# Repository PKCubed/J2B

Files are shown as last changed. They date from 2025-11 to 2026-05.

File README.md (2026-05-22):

# J2B
### Wenatchee Seventh Day Adventist Church's Journey to Bethlehem Timekeeping Technology Systems

## Diagrams and Documentation
**A wiring diagram can be found [here](https://github.com/PKCubed/J2B/blob/master/J2B%20Wiring%20Diagram.pdf)**. This diagram shows the connections between many of the devices that need to be set up in the village every year, as well as connections that should be permanently set up.

**A wiring map can be found [here](https://github.com/PKCubed/J2B/blob/master/J2B%20Wiring%20Map.pdf)**. This diagram shows the connections in the village, and where each connection goes to and from on a high resolution aerial image of the village. *This diagram does not render the background image correctly in GitHub. It will likely need to be downloaded first.*

## System Overview
Journey to Bethlehem requires the actors to transition each group of journeyers along to the next part of their journey. The actors need to know when to do this, and keep the whole operation on a pretty rigid schedule. If things are out of sync, we’ll have too many groups in some areas, getting jumbled together, or not enough groups in the village, and we won’t be able to get through the number of groups we’d like to as fast as we would like to. There are a lot of people who want to experience Bethlehem, and getting everyone the opportunity is our goal.

In order to get all the groups through, a system for keeping everything synchronized and in time is necessary. In past years, this has been done with walkie-talkies given to specific actors called time-keepers in the village. Someone with a walkie-talkie would be watching a clock, and every 4 minutes or so, would say “30 30 30,” to let all the time-keepers in the village know that they had 30 seconds until the groups would need to move on, and “GO GO GO,” to let the time-keepers know it was time to move the groups to the next section of their journey. The advantages of this system were that, ideally, each time-keeper would be able to have an earpiece, and would be able to clearly hear the message. However, in practice, the walkie-talkie system was very spotty, and groups would end up out of sync.

In Christmas of 2024, we built a new system. Peter Kyle designed an automated system using little plastic candles, and audio cues in the village. These all connect to a controller that lives in the FLC (Family Life Center). The controller can be started in automatic mode (or manual mode) to make the candles flicker out in time to let the time-keepers in the village get the message. One candle burns out at “30 30 30,” and the other candle then burns out at “GO GO GO.” After about 10 seconds, both candles come back to a flickering flame again.

Controller
Candle

With this new system, a web interface was also built. People can open their web browser on their phone or computer and navigate to the public-facing web interface to view the timekeeping clock. People responsible for calling groups and setting the current performer text on the projector screen can also use this web interface to do this.

Screenshot of Web Interface

When a group gets called, it's important to get people's attention in the sanctuary. Putting up the big group number text on the screen is not quite enough to get people's attention if they aren't looking at it. To accomplish this, whenever a group is called, the program on the projection PC sends a GET request to the church Home Assistant server, which then is received by Node-RED, and triggers a Home Assistant script that brings the houselights and christmas lights up in brightness, and triggers an animation on the valance lights. After about 30 seconds, the houselights dim down again.

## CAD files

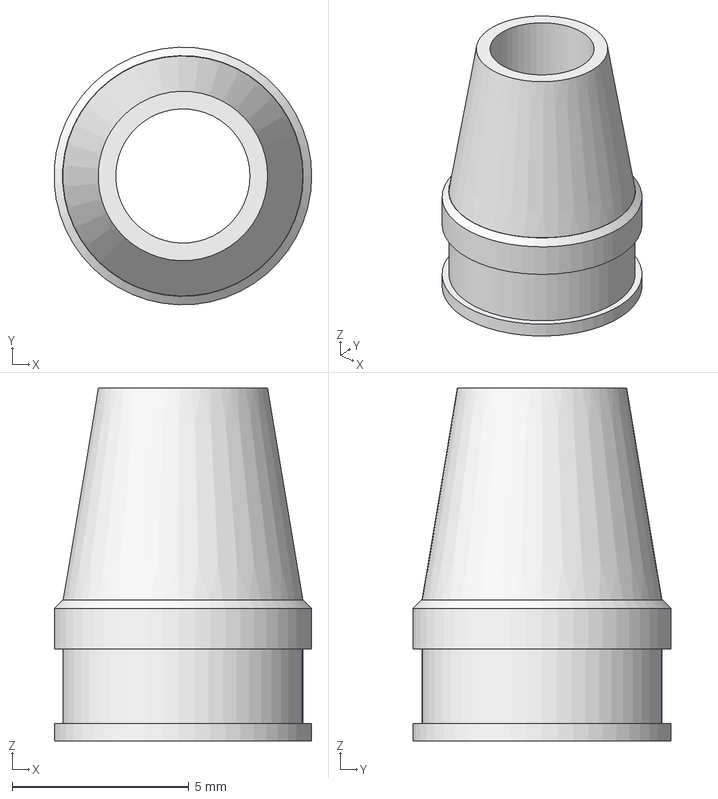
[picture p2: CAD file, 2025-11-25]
3D Models/TPU Cable Stress Relief.FCStd
7.29 x 7.30 x 10.0 mm

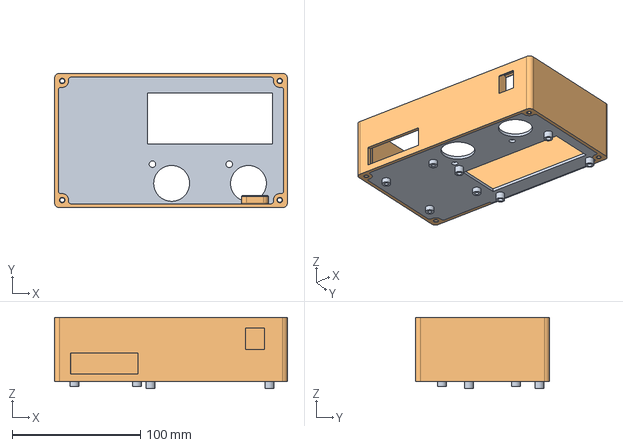
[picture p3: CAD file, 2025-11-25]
3D Models/j2b controller.FCStd
182.0 x 105.0 x 55.5 mm

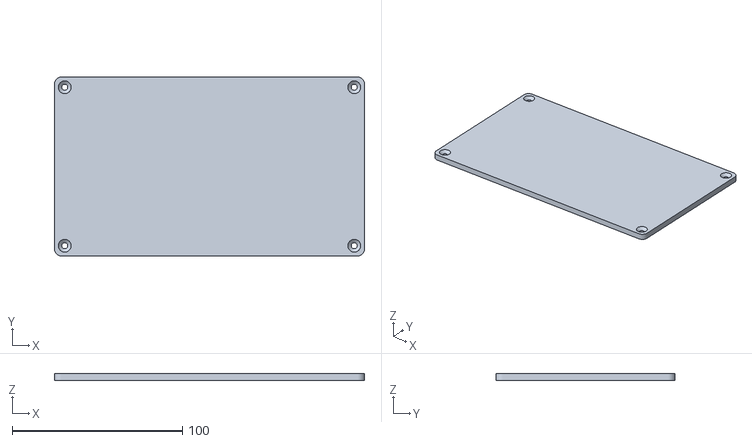
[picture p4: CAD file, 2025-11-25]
3D Models/j2b-controller-back-plate.stl
182.0 x 105.0 x 4.00

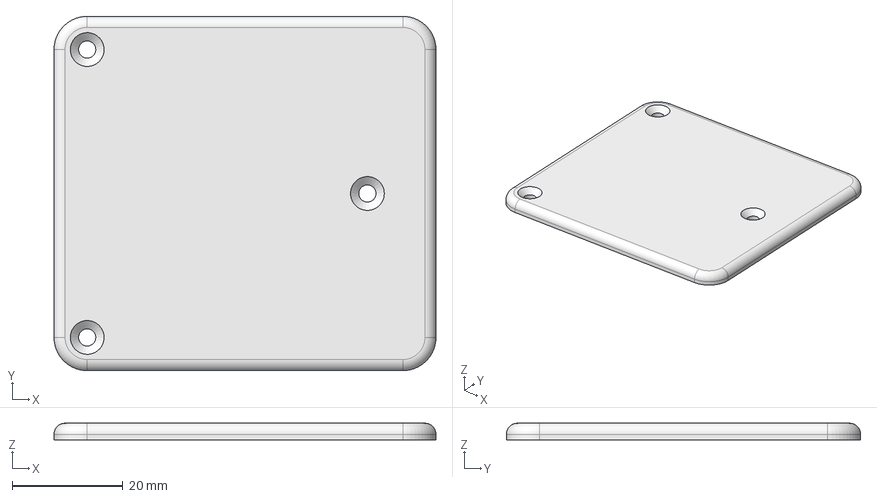
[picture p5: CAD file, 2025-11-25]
3D Models/Keystone Passthrough Lid.FCStd
69.0 x 64.0 x 3.00 mm

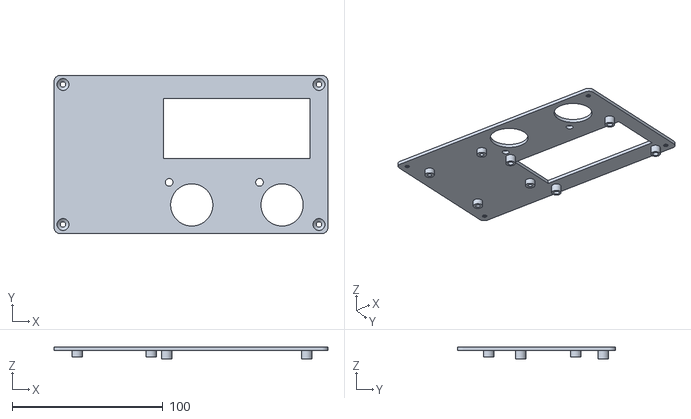
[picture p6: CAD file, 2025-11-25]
3D Models/j2b-controller-front-plate.stl
182.0 x 105.0 x 8.00

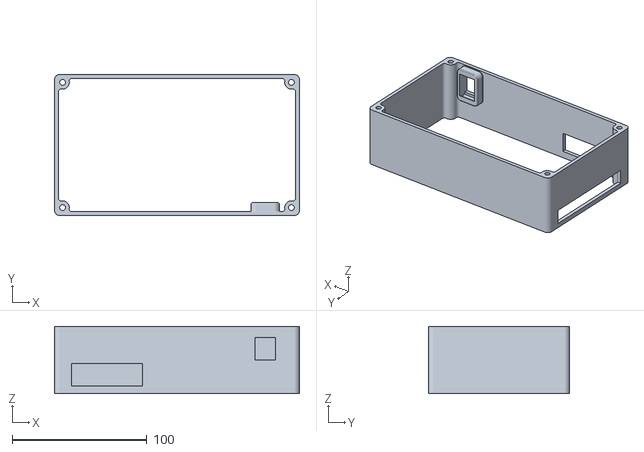
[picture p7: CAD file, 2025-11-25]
3D Models/j2b-controller-shell.stl
182.0 x 105.0 x 50.0

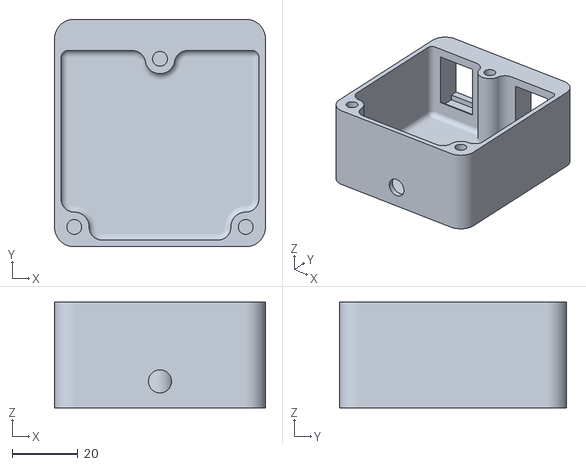
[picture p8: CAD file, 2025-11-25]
3D Models/keystone passthrough 2 corrected.stl
64.0 x 69.0 x 32.0

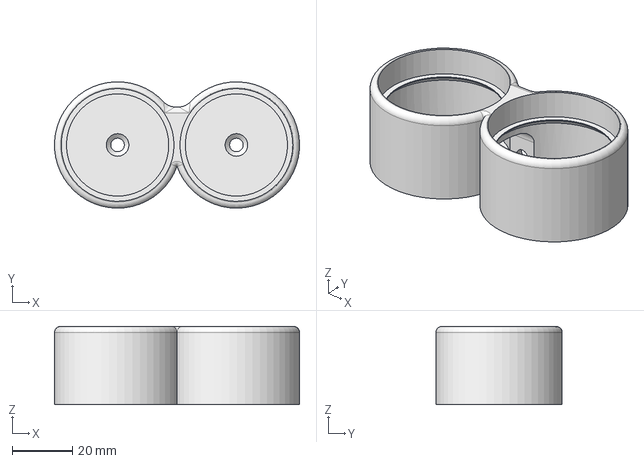
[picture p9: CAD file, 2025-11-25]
3D Models/Candle Holder.FCStd
81.5 x 42.0 x 26.0 mm

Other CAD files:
3D Models/TPU Cable Stress Relief.stl
3D Models/candle holder.stl

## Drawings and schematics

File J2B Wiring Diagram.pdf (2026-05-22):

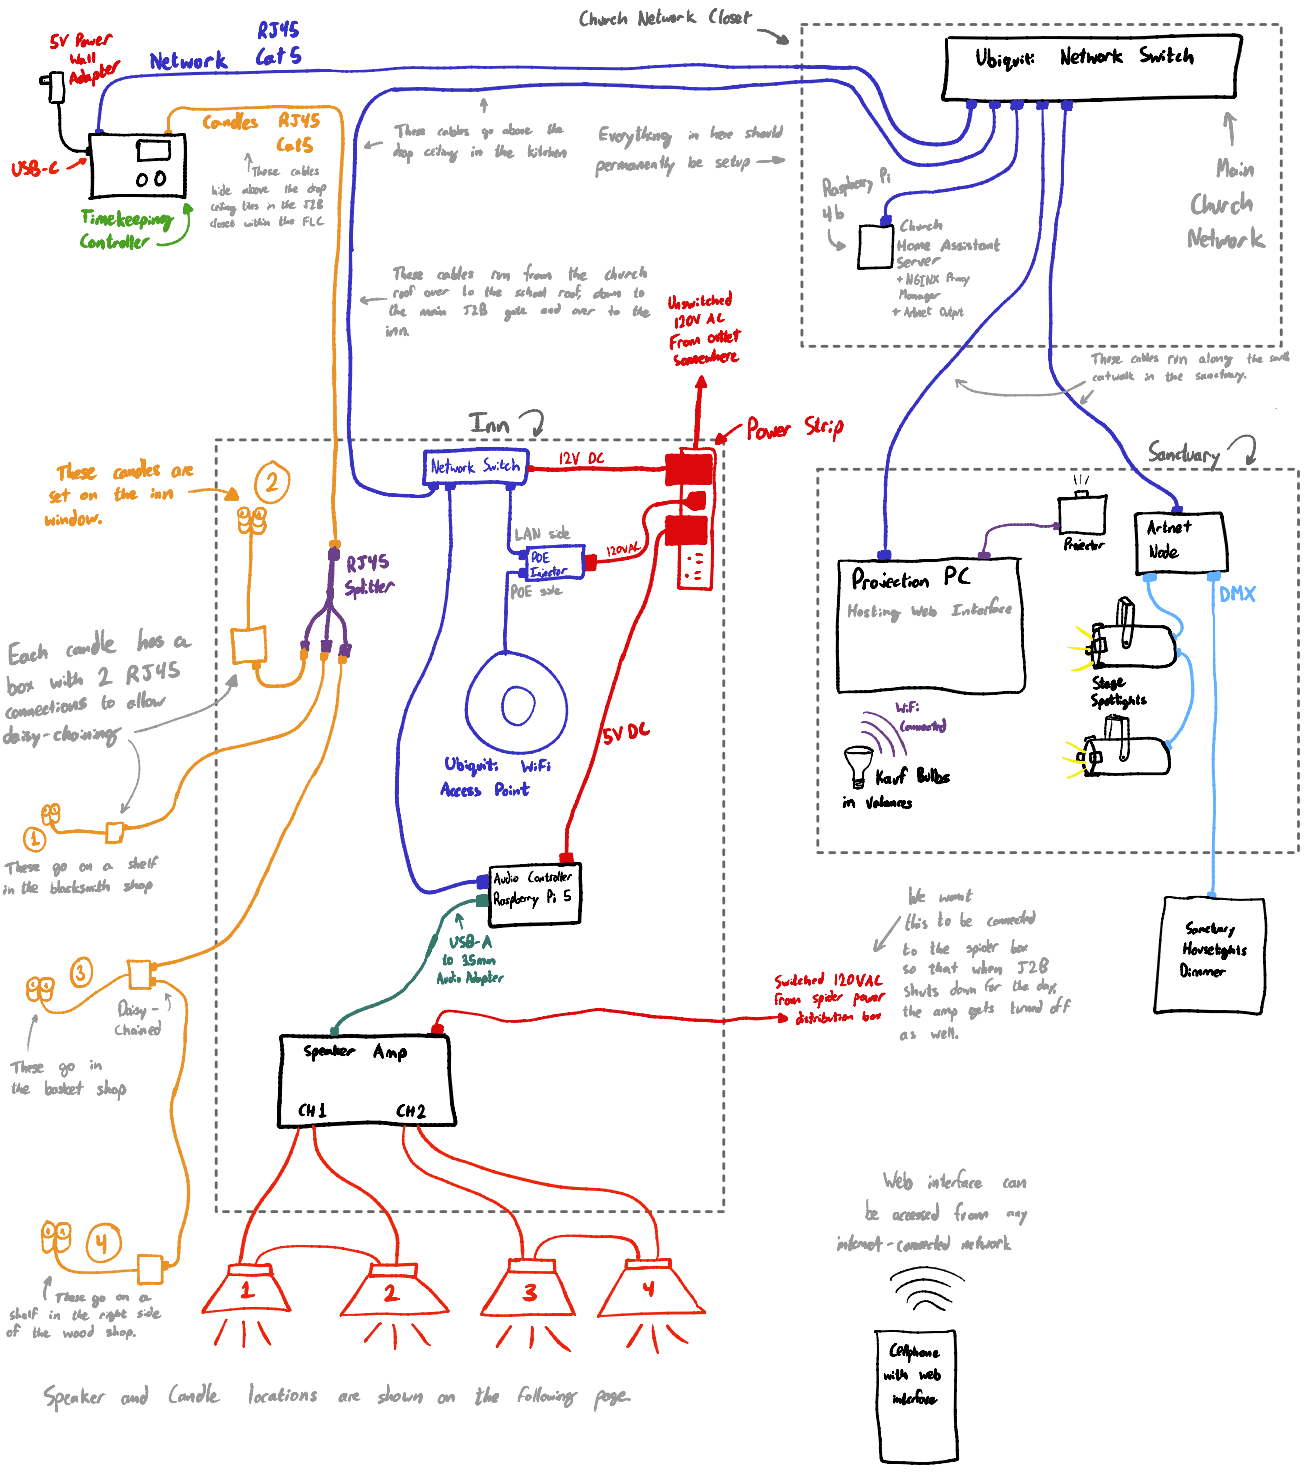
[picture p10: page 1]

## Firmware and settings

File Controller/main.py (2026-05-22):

"""
Written by Peter Kyle 2024 for Journey to Bethlehem Timekeeping
Wenatchee WA Seventh Day Adventist Church
Any questions or comments, please contact me at
peter@pkcubed.net
(***) ***-****
These contacts may not work in the future, but please try to reach out to me however possible.

Feel free to leave your name below to let others know that you've been here and what you did:
- Peter Kyle 2024
	If your seeing this, you're either really curious or something is not working... Good luck to you!
	This was a lot of fun to create and I hope it continues to be used in the distant future. J2B is a blessing to a lot of people.

	Description of this program:
	This is designed to run on a Raspberry Pi 4b with 2 buttons attached, each with an led, and a 20x4 character LCD.
	It's purpose is to control candles in the J2B village as well as audio cues to tell the groups to move on after 4 minutes.
	Traditionally this has been done by FRS radio with a timekeeper speaking into the radio "30 30 30" and "GO GO GO" when 30 seconds were left on the clock and when the 4 minutes had elapsed respectively.
	Hopefully this will prove to be a better solution, both easier to use, and more effective. I've heard that the radios were very much not reliable.
	This also sends the timekeeping time, or rather makes it available for other things to see. Primarily the computer in the balcony responsible for projection which has a program running on it for displaying the group number and the performers on stage.
	That program then has a web interface that allows users to modify the group number, change the performer, and show them the timekeeping time. This way they know when to call the next group of people from the sanctuary.
	This program sends GET requests to another raspberry pi which is responsible for playing the audio cues. It is connected to a speaker amp and a bunch of speakers.


"""

start_text="J2B Timekeeper Panel" # This is the text to be displayed at startup
running_text = "J2B Timekeeper Panel"

message = ""
last_message = ""

audio_player_ip_address = "10.12.2.1" # This is the IP address of the raspberry pi in the village that plays audio through speakers in the village. If this is not set correctly, audio will not work!

from RPLCD.i2c import CharLCD
import RPi.GPIO as GPIO
GPIO.setwarnings(False)
import time
start_time = time.time()
import math
import datetime
from flask import Flask
import threading
import requests

candles_1_pin = 22
candles_2_pin = 27

mode_button_pin = 24
mode_led_pin = 5
trigger_button_pin = 23
trigger_led_pin = 6

button_debounce_time = 0.100 # The duration to lengthen any button press to in order to reject button bouncing

total_duration = 4 *60 # 4 Minutes
timer_duration = 30 # 30 Seconds
go_duration = 10 # 10 Seconds

mode = "Manual"

trigger_timer = 0

trigger_button_state = 0
trigger_button_last_state = 0
trigger_button_debounce_timer = 0

mode_button_state = 0
mode_button_last_state = 0
mode_button_debounce_timer = 0
cycles = 0
cycles_pre_go = 0
last_count = total_duration + 1
last_status = ""

def send_message(text):
	global message
	tstamp = time.time()
	print(tstamp)
	message = (str(datetime.datetime.fromtimestamp(tstamp).strftime("%-H:%M:%S"))+"-"+text)[0:20]
	print(datetime.datetime.fromtimestamp(tstamp))
	

app = Flask(__name__)

@app.route('/')
def time_page():
	if trigger_timer:
		return str(time.time()-trigger_timer)
	else:
		return "-1"

def update_status():
	global cycles
	global last_count
	global last_status
	global cycles_pre_go
	global trigger_timer
	global message
	global last_message
	
	if mode == "Manual": # If we're in manual mode
	
		if time.time() <= trigger_timer + timer_duration: # We're currently within the 30 second (timer_duration) warning period (30 30 30)
			status = "30 30 30!"
			if status != last_status:
				print(status)
				candle_burnout_1()
				audio_303030()
				last_status = status
				lcd.home()
				lcd.write_string(status+(" "*(9-len(status))))
		
			countdown = math.ceil(timer_duration+trigger_timer-time.time())
			if countdown != last_count:
				last_count = countdown
				lcd.cursor_pos = (1,0) # 2nd Line
				lcd.write_string(str(datetime.datetime.fromtimestamp(countdown).strftime("%-M:%S"))+(" "*(8-len(str(datetime.timedelta(seconds=countdown))))))
			led_value = math.ceil((timer_duration+trigger_timer-time.time()) % 0.5 * 4 - 1)
			GPIO.output(trigger_led_pin, led_value)
		elif time.time() <= trigger_timer + timer_duration + go_duration: # It's currently go time, within 10 (go duration) seconds after
			status = "Go Go Go!"
			if status != last_status:
				print(status)
				candle_burnout_2()
				audio_GOGOGO()
				last_status = status
				lcd.home()
				lcd.write_string(status+(" "*(9-len(status))))
				lcd.cursor_pos = (1,0) # 2nd Line
				lcd.write_string(" "*9)
			
			GPIO.output(trigger_led_pin, 1)
		else:
			status = "Idle"
			if status != last_status:
				print(status)
				reset_candles()
				trigger_timer = 0
				last_status = status
				lcd.home()
				lcd.write_string(status+(" "*(9-len(status))))
				lcd.cursor_pos = (1,0) # 2nd Line
				lcd.write_string(" "*9)
			GPIO.output(trigger_led_pin, 0) # Turn off the trigger led because we're in idle mode
			
	elif mode == "Automatic": # If we're in automatic mode
		if trigger_timer:
			mode_led_value = math.ceil((trigger_timer-time.time()) % 0.5 * 4 - 1)
			GPIO.output(mode_led_pin, mode_led_value)
		
			if time.time() <= trigger_timer + timer_duration + ((total_duration) * (cycles)) and time.time() >= trigger_timer + (total_duration * cycles): # Countdown
				status = "30 30 30!"
				if status != last_status:
					print(status)
					candle_burnout_1()
					audio_303030()
					last_status = status
					lcd.home()
					lcd.write_string(status+(" "*(9-len(status))))
			
				countdown = math.ceil(timer_duration + ((total_duration) * (cycles))+trigger_timer-time.time())
				if countdown != last_count:
					last_count = countdown
					lcd.cursor_pos = (1,0) # 2nd Line
					lcd.write_string(str(datetime.datetime.fromtimestamp(countdown).strftime("%-M:%S"))+(" "*(8-len(str(datetime.timedelta(seconds=countdown))))))
					#print(str(countdown))
				led_value = math.ceil((timer_duration + ((total_duration) * (cycles))+trigger_timer-time.time()) % 0.5 * 4 - 1)
				GPIO.output(trigger_led_pin, led_value)
	
	
				
			elif time.time() <= trigger_timer + timer_duration + go_duration + ((total_duration) * (cycles)) and time.time() >= trigger_timer + timer_duration + (total_duration * (cycles)): # GO GO GO
			
				status = "Go Go Go!"
				if status != last_status:
					print(status)
					candle_burnout_2()
					audio_GOGOGO()
					last_status = status
					lcd.home()
					lcd.write_string(status+(" "*(9-len(status))))
					cycles_pre_go += 1
					if cycles_pre_go >= 100:	
						lcd.cursor_pos = (1,9) # 2nd Line
						lcd.write_string("  Cycles: " + str(cycles_pre_go) + (" "*(10-len("Cycles: "+str(cycles_pre_go)))))
					elif cycles_pre_go >= 10:	
						lcd.cursor_pos = (1,10) # 2nd Line
						lcd.write_string(" Cycles: " + str(cycles_pre_go) + (" "*(10-len("Cycles: "+str(cycles_pre_go)))))
					else:
						lcd.cursor_pos = (1,11) # 2nd Line
						lcd.write_string("Cycles: " + str(cycles_pre_go) + (" "*(10-len("Cycles: "+str(cycles_pre_go)))))
					
					print("Cycles: " + str(cycles_pre_go) + (" "*(10-len("Cycles: "+str(cycles_pre_go)))))
					
				countdown = math.ceil(timer_duration + ((total_duration) * (cycles+1))+trigger_timer-time.time())
				if countdown != last_count:
					last_count = countdown
					lcd.cursor_pos = (1,0) # 2nd Line
					lcd.write_string(str(datetime.datetime.fromtimestamp(countdown).strftime("%-M:%S"))+(" "*(8-len(str(datetime.timedelta(seconds=countdown))))))
					#print(str(countdown))
					
				GPIO.output(trigger_led_pin, 1)
	
				
			elif time.time() >= trigger_timer + timer_duration + go_duration + (total_duration * (cycles)):
				if trigger_timer:
					cycles += 1
	
	
					
			else:
				GPIO.output(trigger_led_pin, 0)
				
				status = "Running"
				if status != last_status:
					print(status)
					reset_candles()
					last_status = status
					lcd.home()
					lcd.write_string(status+(" "*(10-len(status))))
				
				countdown = math.ceil(timer_duration + ((total_duration) * (cycles))+trigger_timer-time.time())
				if countdown == timer_duration:
					lcd.cursor_pos = (1,0) # 2nd Line
					lcd.write_string(" "*10)
				else:
					if countdown != last_count:
						last_count = countdown
						lcd.cursor_pos = (1,0) # 2nd Line
						lcd.write_string(str(datetime.datetime.fromtimestamp(countdown).strftime("%-M:%S"))+(" "*(8-len(str(datetime.timedelta(seconds=countdown))))))
						#print(str(countdown))
		else: # If we're not actively in auto or manual mode, we're in "idle" mode.
			status = "Idle"
			if status != last_status:
				print(status)
				reset_candles()
				last_status = status
				lcd.home()
				lcd.write_string(status+(" "*(9-len(status))))
				lcd.cursor_pos = (1,0) # 2nd Line
				lcd.write_string(" "*9)
			GPIO.output(trigger_led_pin, 0)

	if message != last_message:
		lcd.cursor_pos = (2,0)
		lcd.write_string(message(" "*(20-len(status)))
		last_message = message

# Start and clear the character LCD
lcd = CharLCD(i2c_expander='PCF8574', address=0x27, port=1, cols=20, rows=4, dotsize=8)
lcd.clear()

lcd.write_string(start_text) # Display startup text
lcd.cursor_pos = (3,0) # Bottom Line
lcd.write_string('Starting...')

# Configure GPIO
GPIO.setmode(GPIO.BCM) # Use broadcom chip pin numbers
GPIO.setup(mode_led_pin, GPIO.OUT) # Set the mode led pin to be an output
GPIO.setup(trigger_led_pin, GPIO.OUT) # Set the trigger led pin to be an output
GPIO.setup(mode_button_pin, GPIO.IN, pull_up_down=GPIO.PUD_UP) # Set the mode button pin to be an input and enable internal pullup resistor
GPIO.setup(trigger_button_pin, GPIO.IN, pull_up_down=GPIO.PUD_UP) # Set the trigger button pin to be an input and enable internal pullup resistor
GPIO.setup(candles_1_pin, GPIO.OUT) # Set the first candle pin to be an output
GPIO.setup(candles_2_pin, GPIO.OUT) # Set the second candle pin to be an output

GPIO.output(mode_led_pin, 1) # Turn on the mode led (startup test)
GPIO.output(trigger_led_pin, 1) # Turn on the trigger led (startup test)

def reset_candles():
	GPIO.output(candles_1_pin, 1) # Turn on candle 1
	GPIO.output(candles_2_pin, 1) # Turn on candle 2

def candle_burnout_1():
	GPIO.output(candles_1_pin, 0) # Turn off candle 1
	GPIO.output(candles_2_pin, 1) # Leave candle 2 on

def candle_burnout_2():
	GPIO.output(candles_1_pin, 0) # Turn off candle 1
	GPIO.output(candles_2_pin, 0) # Turn off candle 2


def get_303030():
	try:
		response = requests.get("http://"+audio_player_ip_address+":5000/303030", timeout=2) # Timeout after 2 seconds
		if response.status_code != 200:
			send_message("Audio Conn Err")
			print("Status code error")
	except Exception as err:
		send_message("Audio Error")
		print("Error while sending GET request to play audio 303030: ")
		print(err)
		print()
	
def get_GOGOGO():
	try:
		response = requests.get("http://"+audio_player_ip_address+":5000/GOGOGO", timeout=2) # Timeout after 2 seconds
		if response.status_code != 200:
			send_message("Audio Conn Err")
			print("Status code error")
	except Exception as err:
		send_message("Audio Error")
		print("Error while sending GET request to play audio GOGOGO: ")
		print(err)
		print()
	

def audio_303030():
	request_thread = threading.Thread(target=get_303030)
	request_thread.start()
	
def audio_GOGOGO():
	request_thread = threading.Thread(target=get_GOGOGO)
	request_thread.start()
	

reset_candles()

def run_server():
	app.run(host='0.0.0.0')

server_thread = threading.Thread(target=run_server)
server_thread.start()


while time.time() <= start_time + 1:
	continue

lcd.clear()
lcd.cursor_pos = (3,0)
lcd.write_string(start_text)

lcd.cursor_pos = (0, 20-len(mode))
lcd.write_string(mode)

GPIO.output(mode_led_pin, 0)
GPIO.output(trigger_led_pin, 0)

while True:
	if not GPIO.input(mode_button_pin):
		mode_button_debounce_timer = time.time()
		mode_button_state = 1
	elif mode_button_debounce_timer + button_debounce_time < time.time():
		mode_button_state = 0

	if not GPIO.input(trigger_button_pin):
		trigger_button_debounce_timer = time.time()
		trigger_button_state = 1
	elif trigger_button_debounce_timer + button_debounce_time < time.time():
		trigger_button_state = 0
	
	if trigger_button_state:
		if not trigger_button_last_state: # Trigger Button Rising Edge
			#print("Rising Edge Trigger")
			if trigger_timer:#time.time() <= trigger_timer + timer_duration: # Cancel the current que
				#print("Trigger timer")
				if (time.time() - trigger_timer) < timer_duration and mode == "Manual":
					#print("during 30 30 30")
					trigger_timer = time.time()-timer_duration
					#print("GO Time")
				else:
					trigger_timer = 0
					cycles = 0
					cycles_pre_go = 0
					lcd.cursor_pos = (1,10) # 2nd Line
					lcd.write_string((" "*10))
					if mode == "Manual":
						GPIO.output(mode_led_pin, 0)
					elif mode == "Automatic":
						GPIO.output(mode_led_pin, 1)
			else:
				trigger_timer = time.time()
		else: # Trigger Button Falling Edge
			pass
	trigger_button_last_state = trigger_button_state
	if mode_button_state:
		if not mode_button_last_state: # Trigger Button Rising Edge
			if mode == "Manual":
				mode = "Automatic"
				cycles = 0
				cycles_pre_go = 0
				lcd.cursor_pos = (1,10) # 2nd Line
				lcd.write_string((" "*10))
				trigger_timer = 0
				reset_candles()
				GPIO.output(mode_led_pin, 1)
			elif mode == "Automatic":
				mode = "Manual"
				cycles = 0
				cycles_pre_go = 0
				lcd.cursor_pos = (1,10) # 2nd Line
				lcd.write_string((" "*10))
				trigger_timer = 0
				reset_candles()
				GPIO.output(mode_led_pin, 0)
				
			lcd.cursor_pos = (0, 10)
			lcd.write_string((" "*(10-len(mode)))+mode)
		else: # Trigger Button Falling Edge
			pass
	mode_button_last_state = mode_button_state

	update_status()

		
GPIO.cleanup()

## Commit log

2025-11-25 background audio not uploaded (too big)
    [main.py]
2025-11-25 Added 3D Files
    Couldn't find the FCStd file for the keystone passthrough, but I did find an stl.
    [Keystone Passthrough Lid.FCStd, TPU Cable Stress Relief.FCStd, TPU Cable Stress Relief.stl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]
2026-05-22 Added wiring documentation drawings
2026-05-22 Add diagrams and documentation section to README
    Added diagrams and documentation section with links to wiring diagram and map.
2026-05-22 Highlight wiring diagram and map links in README
    Emphasized the wiring diagram and map links for better visibility.
2026-05-22 Update wiring map description in README
    Added note about background image rendering issue for wiring map.
2026-05-22 Added PNG version of wiring map
2026-05-22 Added Wiring Map Inkscape File
